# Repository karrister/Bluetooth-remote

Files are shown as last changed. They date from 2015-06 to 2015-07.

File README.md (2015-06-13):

Bluetooth-remote
=============

A project to make a simple multi-purpose Bluetooth remote controller device.

Currently there are two purposes for this project - one is to serve as a Bluetooth shutter for my Nikon SLR, and the second is to integrate the Bluetooth remote to work with my other project, the StigaGoalSong, to be able to control with over the Bluetooth, when a team scores in the game of table hockey (please take a look at my other project in github, StigaGoalSong).

This repository will have one common PCB design for both purposes, and it will also end up including the PIC FW for both cases (unless I will be able to pack both features in one FW).

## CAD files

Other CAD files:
Firmware/bt_remote.X/dist/default/production/bt_remote.X.production.obj
Firmware/bt_remote.X/l.obj

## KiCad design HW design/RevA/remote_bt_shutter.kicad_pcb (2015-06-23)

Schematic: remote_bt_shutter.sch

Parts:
C1: TBD
C2, C3: 15pF
C4, C5: 0.1uF
C6: 100pF
C7: 33nF
C8, C9: CP1
D1, D2: TBD
D3, D4: LED
D5: DIODESCH
D6: 0
K1: NIKON_CONN
L1: INDUCTOR
P1: ICSP
P3: MODE_SW
P4: SW1
P5: TP_BT_RX
P6: TP_BT_TX
P7: SW2
P8: SW3
P9: BATT_CONN
P10: PWR_SW
R1: TBD
R2: 0
R3, R4, R6, R7, R8, R11, R13: 10k
R5: 4k6
R9, R10: 200
R12, R15, R16, R17: R
R14: 1K8
T1, T2: BSV52
U1: PIC18F14K50
U2: EGBT-046S
U3: TPS61006
X1: CRYSTAL

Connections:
+3.3V: C4.1, C5.2, C8.1, D5.2 (K), D6.1 (A), D6.2 (K), P1.2, R1.1, R6.1, R7.1, R8.1, R11.1, R15.1, U1.1 (Vdd), U2.12 (Vcc), U3.5 (Vout)
/LOW_BATT_IND: D1.1 (A), R15.2, U3.10 (LBO)
GND: C1.2, C2.2, C3.2, C4.2, C5.1, C6.2, C7.2, C8.2, C9.2, D3.2 (K), D4.2 (K), K1.1, P1.3, P3.1, P4.1, P7.1, P8.1, P9.2 (PM), R16.2, T1.2 (E), U1.20 (Vss), U2.13 (GND), U2.22 (GND), U3.4 (GND)
unnamed: D1.2 (K), D2.2 (K), P1.1, U1.4 (RA3/MCLR)
unnamed: C1.1, D2.1 (A), R1.2
unnamed: P9.1, P10.2 (PM)
unnamed: P1.5, U1.18 (RA1/D-)
unnamed: C7.1, R13.2
unnamed: R14.2, U3.1 (EN)
unnamed: P7.2 (PM), R7.2, U1.15 (RC1/AN5/INT1)
unnamed: P4.2 (PM), R6.2, U1.16 (RC0/AN4/INT0)
unnamed: P1.4, U1.19 (RA0/D+)
unnamed: R9.1, U1.13 (RB4/AN10/SDI/SDA)
unnamed: D3.1 (A), R9.2
unnamed: R12.2, U1.9 (RC7/AN9/SDO)
unnamed: R12.1, U2.24 (LED1)
unnamed: C9.1, L1.1, P10.1, R14.1, R17.1, U3.6 (Vbat)
unnamed: R16.1, R17.2, U3.9 (LBI)
unnamed: R10.1, U1.7 (RC3/AN7)
unnamed: K1.3, T2.3 (C)
unnamed: C6.1, R13.1, U3.2 (COMP)
unnamed: D4.1 (A), R10.2
unnamed: P8.2 (PM), R11.2, U1.11 (RB6/SCK)
unnamed: P3.2 (PM), R8.2, U1.14 (RC2/AN6/INT2)
unnamed: R4.2, T2.1 (B)
unnamed: R3.1, U1.5 (RC5/CCP1)
unnamed: C3.1, R2.1, R2.2, U1.3 (RA4/OSC2), X1.2
unnamed: C2.1, U1.2 (RA5/OSC1), X1.1
unnamed: K1.2 (PM), T1.3 (C), T2.2 (E)
unnamed: R3.2, T1.1 (B)
unnamed: P6.1, U1.12 (RB5/AN11/RX), U2.1 (TXD)
unnamed: P5.1, U1.10 (RB7/TX), U2.2 (RXD)
unnamed: R5.1, U1.8 (RC6/AN8/SS)
unnamed: R4.1, U1.6 (RC4/P1B)
unnamed: R5.2, U2.11 (RESET)
unnamed: D5.1 (A), L1.2, U3.7 (SW)

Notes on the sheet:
POWER INPUT CIRCUIT 1.5V TO 3.3V BOOST

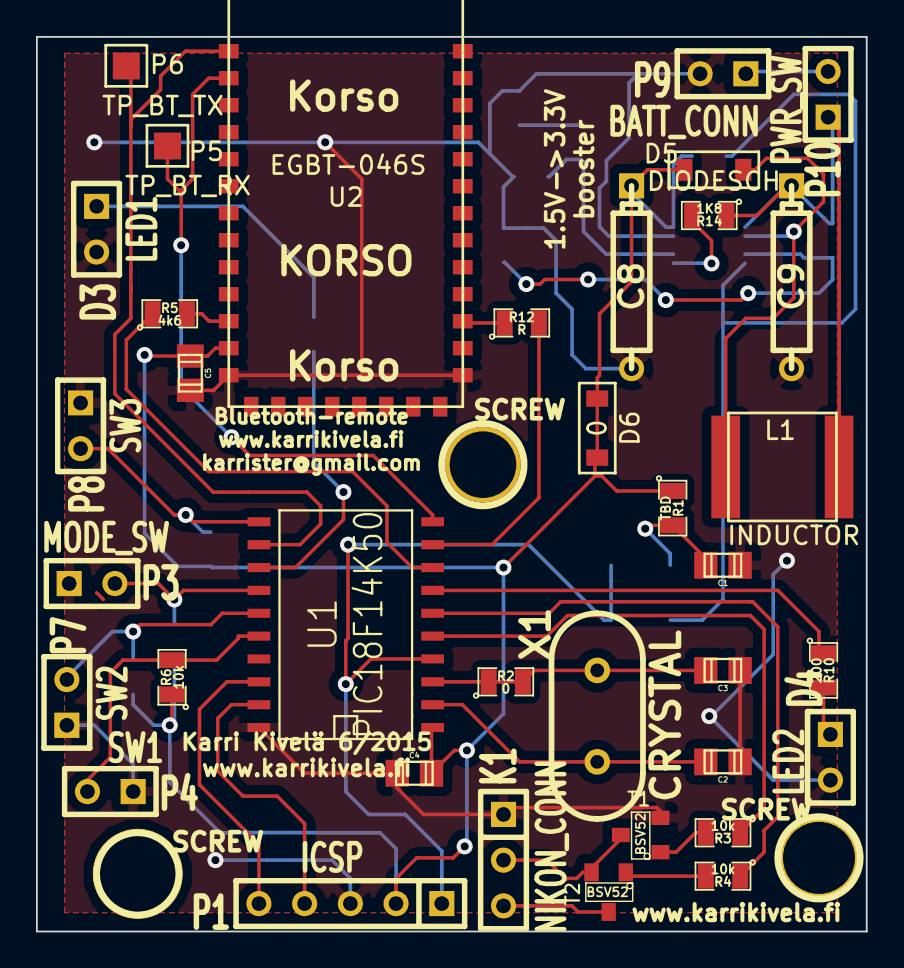
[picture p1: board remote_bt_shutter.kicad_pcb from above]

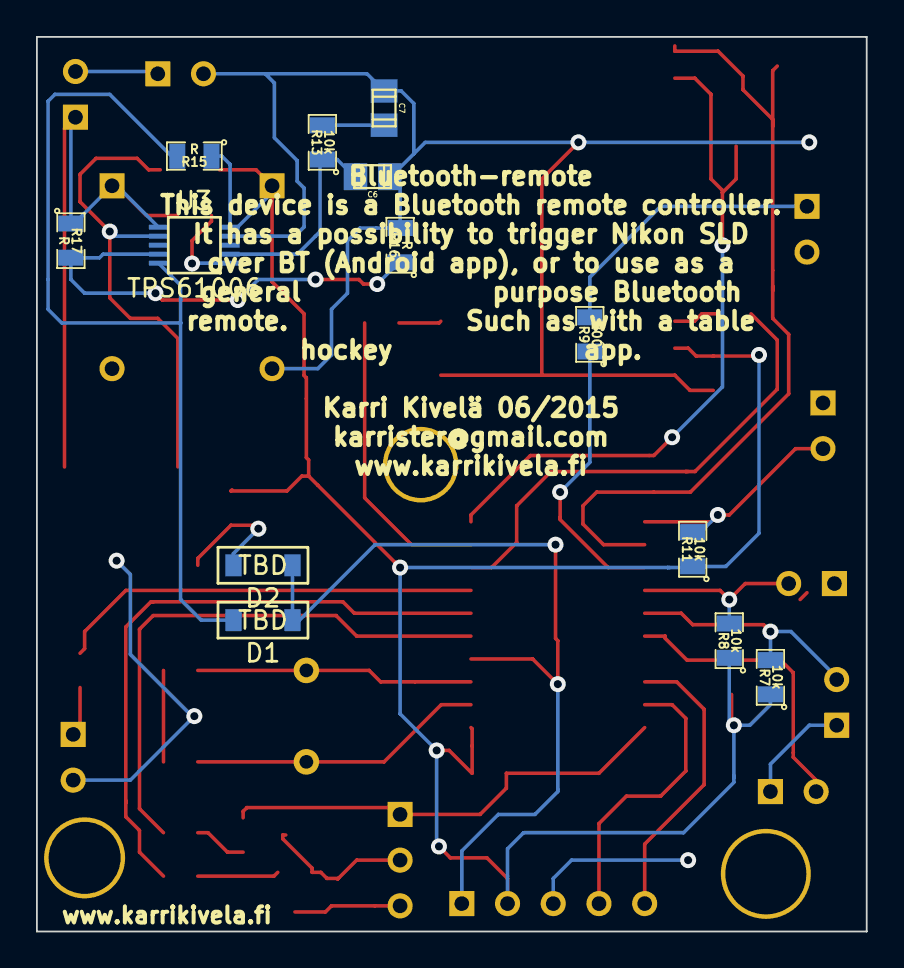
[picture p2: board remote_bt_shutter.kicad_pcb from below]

Board: 2 copper layers, 46.1 x 49.7 mm, 52 parts (13 on the bottom side), 36 nets.

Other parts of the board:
SCREW: P***; 1pin
SCREW#2, SCREW#3: P***; 1pin

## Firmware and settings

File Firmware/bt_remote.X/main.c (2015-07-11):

/* 
 * File:   main.c
 * Author: karrister
 *
 * Created on 24. June 2015, 2:30
 */

#include <stdio.h>
#include <stdlib.h>

#include "project_includes.h"

union device_buttons_state_t
{
    struct
    {
        unsigned char reserved:5;
        unsigned char button3:1;
        unsigned char button2:1;
        unsigned char button1:1;
    };

    unsigned char button_bits;
} device_buttons_state;

union device_error_register_t
{
    struct
    {
        unsigned char reserved:7;
        unsigned char no_connection_to_bt_chip:1;
    };

    unsigned char error_bits;
} device_error_register;

union device_status_t
{
    struct
    {
        unsigned char reserved              :7;
        unsigned char is_bt_device_connected:1;
    };

    unsigned char status_bits;
} device_status;

unsigned char main_state;

void init(void)
{
    /* Init internal status structs */
    device_error_register.error_bits = 0;
    device_status.status_bits = 0;
    main_state = STATE_IDLE;

    /* Set default pinmuxes and other per-pin config */

    /* Output pins */
    //5(RC5) - nikon shutter focus (output, hi = focus camera)
    TRISCbits.TRISC5 = PIN_DIRECTION_OUTPUT;
    //6(RC4) - nikon shutter release (output, hi = release shutter)
    TRISCbits.TRISC4 = PIN_DIRECTION_OUTPUT;
    //7(RC3) - led2 (output, active hi)
    TRISCbits.TRISC3 = PIN_DIRECTION_OUTPUT;
    //13(RB4) - led1 (output, active hi)
    TRISBbits.TRISB4 = PIN_DIRECTION_INPUT;
    //8(RC6) - reset (output, active hi?)
    TRISCbits.TRISC6 = PIN_DIRECTION_OUTPUT;

    /* Input pins */
    //9(RC7) - bt status (input)
    TRISCbits.TRISC7 = PIN_DIRECTION_INPUT;
    //11(RB6) - sw3 (input. switch open = hi, switch closed = lo)
    TRISBbits.TRISB6 = PIN_DIRECTION_INPUT;
    //14(RC2) - mode sw (input. switch open = hi, switch closed = lo)
    TRISCbits.TRISC2 = PIN_DIRECTION_INPUT;
    //15(RC1) - sw2 (input. switch open = hi, switch closed = lo)
    TRISCbits.TRISC1 = PIN_DIRECTION_INPUT;
    //16(RC0) - sw1 (input. switch open = hi, switch closed = lo)
    TRISCbits.TRISC0 = PIN_DIRECTION_INPUT;

    /* General pins */
    //10(RB7) - uart tx
    TRISBbits.TRISB7 = PIN_DIRECTION_OUTPUT;
    //12(RB5) - uart rx
    TRISBbits.TRISB5 = PIN_DIRECTION_INPUT;

}

void poll_buttons(void)
{
    if(1)//TODO: replace with poll of GPIO
    {
        device_buttons_state.button1 = 1;
    }

    if(1)//TODO: replace with poll of GPIO
    {
        device_buttons_state.button2 = 1;
    }

    if(1)//TODO: replace with poll of GPIO
    {
        device_buttons_state.button3 = 1;
    }
}

void set_bt_dev_config(void)
{
    //Set BT baud rate to 9600
    //AT+BAUD4
    UART_SEND_BYTE('A'); //A
    UART_SEND_BYTE('T'); //T
    UART_SEND_BYTE('+');
    UART_SEND_BYTE('B');
    UART_SEND_BYTE('A');
    UART_SEND_BYTE('U');
    UART_SEND_BYTE('D');
    UART_SEND_BYTE('4');

    //Set BT chip name
    //AT+NAMEkarriremote
    UART_SEND_BYTE('A'); //A
    UART_SEND_BYTE('T'); //T
    UART_SEND_BYTE('+');
    UART_SEND_BYTE('N');
    UART_SEND_BYTE('A');
    UART_SEND_BYTE('M');
    UART_SEND_BYTE('E');
    UART_SEND_BYTE('k');
    UART_SEND_BYTE('a');
    UART_SEND_BYTE('r');
    UART_SEND_BYTE('r');
    UART_SEND_BYTE('i');
    UART_SEND_BYTE('r');
    UART_SEND_BYTE('e');
    UART_SEND_BYTE('m');
    UART_SEND_BYTE('o');
    UART_SEND_BYTE('t');
    UART_SEND_BYTE('e');

    //Set PIN password
    //AT+PIN1234
    UART_SEND_BYTE('A'); //A
    UART_SEND_BYTE('T'); //T
    UART_SEND_BYTE('+');
    UART_SEND_BYTE('P');
    UART_SEND_BYTE('I');
    UART_SEND_BYTE('N');
    UART_SEND_BYTE('1');
    UART_SEND_BYTE('2');
    UART_SEND_BYTE('3');
    UART_SEND_BYTE('4');
}

void query_bt_connection_status(void)
{
    BYTE status_readback[2];
    //For now, set status so that the BT device is not connected
    device_status.is_bt_device_connected = 0;

    //Send AT in hexa to inquire status
    UART_SEND_BYTE('A'); //A
    UART_SEND_BYTE('T'); //T

    status_readback[0] = UART_RECV_BYTE();
    status_readback[1] = UART_RECV_BYTE();

    //Expecting to read back OK from uart
    if((status_readback[0] != 'O') || (status_readback[1] != 'K'))
    {
        device_error_register.no_connection_to_bt_chip = 1;
        return;
    }

#ifndef ONLY_PASSIVE_CONNECTION_STATUS_QUERY
    //TODO: implement here an active connection query - query the host application
    //      on the paired BT device.
#else
    device_status.is_bt_device_connected = 1;
#endif
}

void get_config_from_bt(void)
{
    //TODO implement
}

void set_default_config(void)
{
    //TODO implement
}


int main(void)
{
    init();

    /* Configure the Bluetooth chip */
    set_bt_dev_config();

    query_bt_connection_status();

#ifndef NO_GPIO_CONFIG_THROUGH_BT
    if(device_status.is_bt_device_connected)
    {
        get_config_from_bt();
    }
    else
#endif //NO_GPIO_CONFIG_THROUGH_BT
    {
        set_default_config();
    }

    {
    BYTE uart_buff[UART_BUFFER_SIZE];

    while(1)
    {

        switch(main_state)
        {
            case STATE_IDLE:
                //Poll all buttons
                poll_buttons();

                //if preseed, set state and break
                if(device_buttons_state.button_bits)
                {
                    main_state = STATE_BUTTON_PRESSED;
                    break;
                }

                //Attempt to receive UART cmd
                uart_buff[0] = UART_RECV_BYTE();
                uart_buff[1] = UART_RECV_BYTE();
                uart_buff[2] = UART_RECV_BYTE();

                if((uart_buff[0] == 'C') && (uart_buff[1] == 'M') && (uart_buff[2] == 'D'))
                {
                    main_state = STATE_REMOTE_CMD_RECEIVED;
                    //break at the end of case
                }

                break;
            case STATE_BUTTON_PRESSED:

                while(device_buttons_state.button_bits)
                {
                    unsigned char switch_id_char;

                    //Get the next switch ID to transmit
                    if(device_buttons_state.button1)
                    {
                        switch_id_char = '1';
                        device_buttons_state.button1 = 0;
                    }
                    else if(device_buttons_state.button2)
                    {
                        switch_id_char = '2';
                        device_buttons_state.button2 = 0;
                    }
                    else if(device_buttons_state.button3)
                    {
                        switch_id_char = '3';
                        device_buttons_state.button3 = 0;
                    }

                    //Command
                    UART_SEND_BYTE('C');
                    UART_SEND_BYTE('M');
                    UART_SEND_BYTE('D');

                    //Switch toggled
                    UART_SEND_BYTE('S');
                    UART_SEND_BYTE('W');
                    UART_SEND_BYTE('T');

                    //Switch ID
                    UART_SEND_BYTE('S');
                    UART_SEND_BYTE(switch_id_char);
                }

                break;
            case STATE_REMOTE_CMD_RECEIVED:
            default:
                //unexpected state - set WD and reset
                //Debug msg
                UART_SEND_BYTE('D');
                UART_SEND_BYTE('B');
                UART_SEND_BYTE('G');
                //Message
                UART_SEND_BYTE('E');
                UART_SEND_BYTE('R');
                UART_SEND_BYTE('R');
                break;
        }
    } //WHILE(1)

    }

    //Debug msg
    UART_SEND_BYTE('D');
    UART_SEND_BYTE('B');
    UART_SEND_BYTE('G');

    //Message
    UART_SEND_BYTE('F');
    UART_SEND_BYTE('I');
    UART_SEND_BYTE('N');

    return 0;
}

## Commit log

2015-06-13 The initial commit with some PCB logic
    Some previously done work on the PCB logic of a remote Bluetooth shutter
    design. Will base the project on top of this HW design.
    [remote_bt_shutter.sch]
2015-06-14 More work on the PCB logic
    More work, added two switches switch and a LED.
    [remote_bt_shutter.sch]
2015-06-20 Finished PCB logic design
    PCB logic design finished.
    [remote_bt_shutter.sch]
2015-06-20 Netlist before the new footprints
    Parts netlist done, other than for the parts that need footprints
    created.
    [remote_bt_shutter.sch]
2015-06-20 Adding kicad_parts as a subproject
2015-06-20 More netlist done
    More netlist and footprints done, only BT module and coil lacking.
2015-06-22 Some work on PCB layout
    Started to work on PCB layout. Layout almost finished.
    [remote_bt_shutter.kicad_pcb]
2015-06-22 Added a diode from power circuit
    To be on the safe side, added a diode to protect the power circuit from any current from the ICSP prommer. Is actually a shorted connector which can be in time of catastrophy have the trace cut and diode added.
    [remote_bt_shutter.kicad_pcb, remote_bt_shutter.sch]
2015-06-22 PCB layout almost done
    PCB layout done otherwise except for front ground
    [remote_bt_shutter.kicad_pcb]
2015-06-22 PCB layout finished
    Layout finished, still need to add board edges
    [remote_bt_shutter.kicad_pcb]
2015-06-23 PCB layout final
    PCB layout finished, ready for printing.
    [remote_bt_shutter.kicad_pcb]
2015-06-23 PCB printing
    PCB gerber files, printing ordered.
    [remote_bt_shutter-B_Cu.gbl, remote_bt_shutter-B_Mask.gbs, remote_bt_shutter-B_SilkS.gbo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]
2015-06-27 Work on the init
    Some work on the init code
    [bt_remote.X.production.obj, l.obj]
2015-07-11 Basic main logic
    The basic main logic implemented in the PIC Firmware. Need to add some
    more init of peripherals and read of buttons/gpio state.
